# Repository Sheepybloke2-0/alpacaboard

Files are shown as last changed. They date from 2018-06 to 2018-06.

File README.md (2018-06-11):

# Alpaca-board
An Open Source keyboard designed for Kailh Low Profile Switches.

This keyboard is meant to be ultra portable, using the [Kailh Low Profile](https://novelkeys.xyz/products/kailh-low-profile-switches)
switches and a minimalist design. That being said, I wanted to add all the keys that I miss when typing on my 40% and 60% boards, such as arrow
keys, Home, End, Delete, Up and Down. I also decided to use USB C as the connector, since I perfer the form factor and flexablility for future
designs. The keyboard will be fully customizable through QMK, the software of which will be coming up soon.

# Goals
 - Be portable yet useful
 - Have RGB underglow, maybe backlighting?
 - Try out different PCB and key layouts for something new and exciting
 - Utilize current Kailh Low Profile switches and keycaps 
 - Add Bluetooth capablilities!

# Software and Tools
Schematic and PCB design was done in [KiCAD](http://kicad-pcb.org/). Because I'm lazy, the routing was done by [Freerouting](https://github.com/freerouting/freerouting).

# References
 - [ATmega32U4 Datasheet](https://cdn.sparkfun.com/datasheets/Dev/Arduino/Boards/ATMega32U4.pdf)
 - [PJRC Wiki](https://www.pjrc.com/)
 - [OLKB Basic Schematics](https://github.com/olkb/olkb_parts/blob/master/planck/schematic.pdf)
    - Used this as a basic reference on how to use the ATmega in the system. Great starting point for figuring out what to Google!
 - [Kailh Low Profile CAD](https://github.com/keyboardio/keyswitch_documentation/blob/master/datasheets/Kailh/PG135001D02.pdf)
    - I believe this is still the design of the current switches. 
 - [QMK's handwiring guide](https://docs.qmk.fm/#/hand_wire)
    - Helps you understand the basics of keyboard design and the key matrix
 - [USB C connector pinouts](https://en.wikipedia.org/wiki/USB-C#Connector_pinouts)
 - [Guide to the key matrix](http://blog.komar.be/how-to-make-a-keyboard-the-matrix/)
    - Great and informative guide to keyboard design
 - [Featherwing ATmega32u4 with BLE](https://www.adafruit.com/product/2829)
 - [MCP23008 I2C GPIO Expander](https://www.adafruit.com/product/593)
 - [Max keyboard key size chart](http://www.maxkeyboard.com/mechanical-keycap-layout-and-size-chart.html)
 - [Bunch of keyboard parts](https://github.com/keebio/Keebio-Parts.pretty)
 - [Featherwing KiCAD Model](https://forum.kicad.info/t/designing-featherwings-in-kicad/6115/2)
    - Use the bottom one
    
# Version 0.2 
After making the schematic and layout for V0.1, I decided to change the components to thru-hole and use a micro-controller for 
easier soldering and assembly. The other reason is because of the Featherwing ATMega32u4 with BLE support. This has a handle
LiPo charging circuit and BLE support for most devices, specifically mobile. For some computers a converter may be needed. 
However, in order to make this work, I had to add a GPIO expander, since most of the pins on the Featherwing are needed for
other functions, such as the Bluetooth and charging. The expander talks via I2C and is addressed at `000`. This expander also
allows for the RGB underglow I wanted to include. Now, it's on to fabrication and software!

# License
I hope that by keeping this project Open Source, other designers can use my work as a base to get up and running quickly. Feel free to use my 
notes and ideas, but please adhere to the [Open Hardware License](https://www.oshwa.org/definition/).

Enjoy!

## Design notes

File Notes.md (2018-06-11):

# Notes on Working with the ATMega32U4 for Keyboard Design

1. `PB7` is the [standard port](https://docs.qmk.fm/#/feature_backlight) in QMK for the `LED_DATA` line.
2. `PE2` is a reset with connections to the bootloader. I think it is needed for
   flashing the system. [See PE2 on pg 80](https://cdn.sparkfun.com/datasheets/Dev/Arduino/Boards/ATMega32U4.pdf)
3. Use `ATMega32U4RC-AU`. `RC` means it has an internal oscillator, and `AU` means the
   package has the leads exposed.
4. I don't think we need to have `XTAL` connected, since we are using an internal oscillator.
5. Connect all the Vccs and GNDs together, since we aren't doing anything fancy with the ADC
6. Filter the Vcc with a couple of caps. Doesn't need to be huge, but it's 5c for two 10uF caps, so worth it for the extra filtering.
7. For the shield, assume the GND is the same as referance.
8. [See this page](https://github.com/keyboardio/keyswitch_documentation/blob/master/datasheets/Kailh/PG135001D02.pdf) for the switch footprint.
9. Think foot print of PCB is 70mmx250mm
10. 330mmX98mm
11. Mount0 = 58.42mm X 168.4mm
12. Mount1 = 20.32mm X 28.7mm
13. Mount2 = 22.61mm X 39.88mm
14. Mount3 = 4.1mm X 47mm
15. Mount4 = 19.1mm X 22.35mm

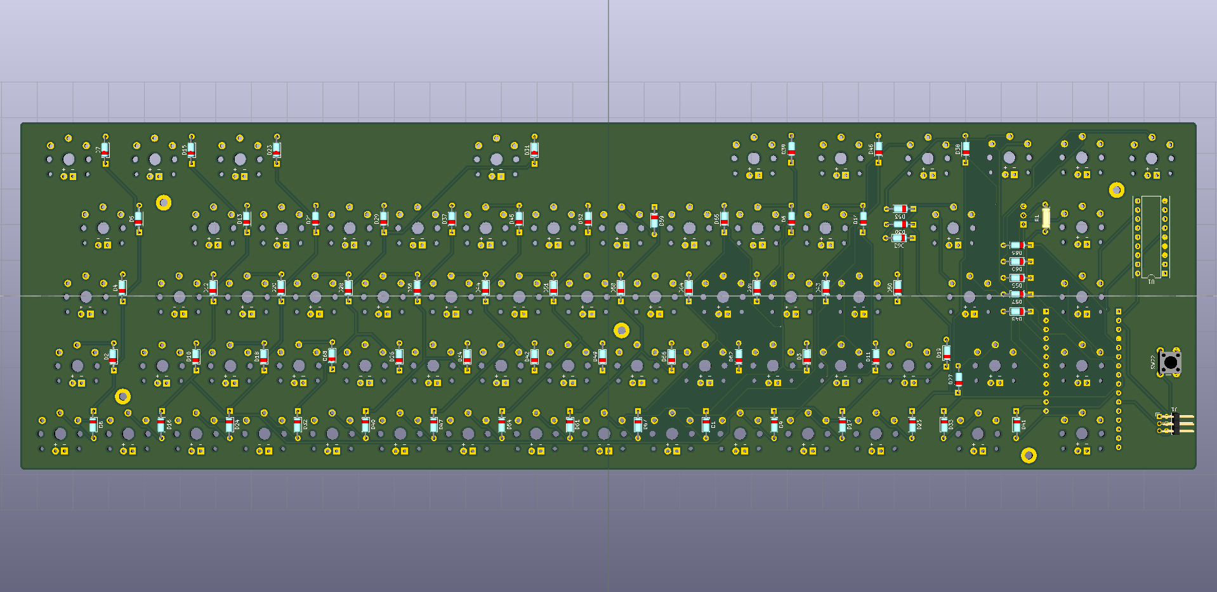
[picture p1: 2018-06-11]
alpacaboard_schem_v0.2_Back.png

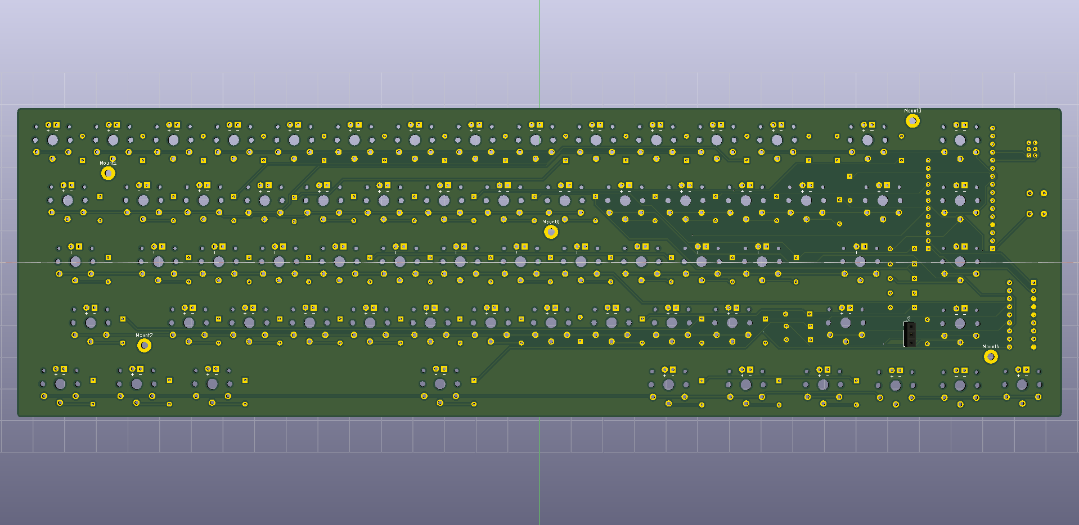
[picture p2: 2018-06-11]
alpacaboard_schem_v0.2_Front.png

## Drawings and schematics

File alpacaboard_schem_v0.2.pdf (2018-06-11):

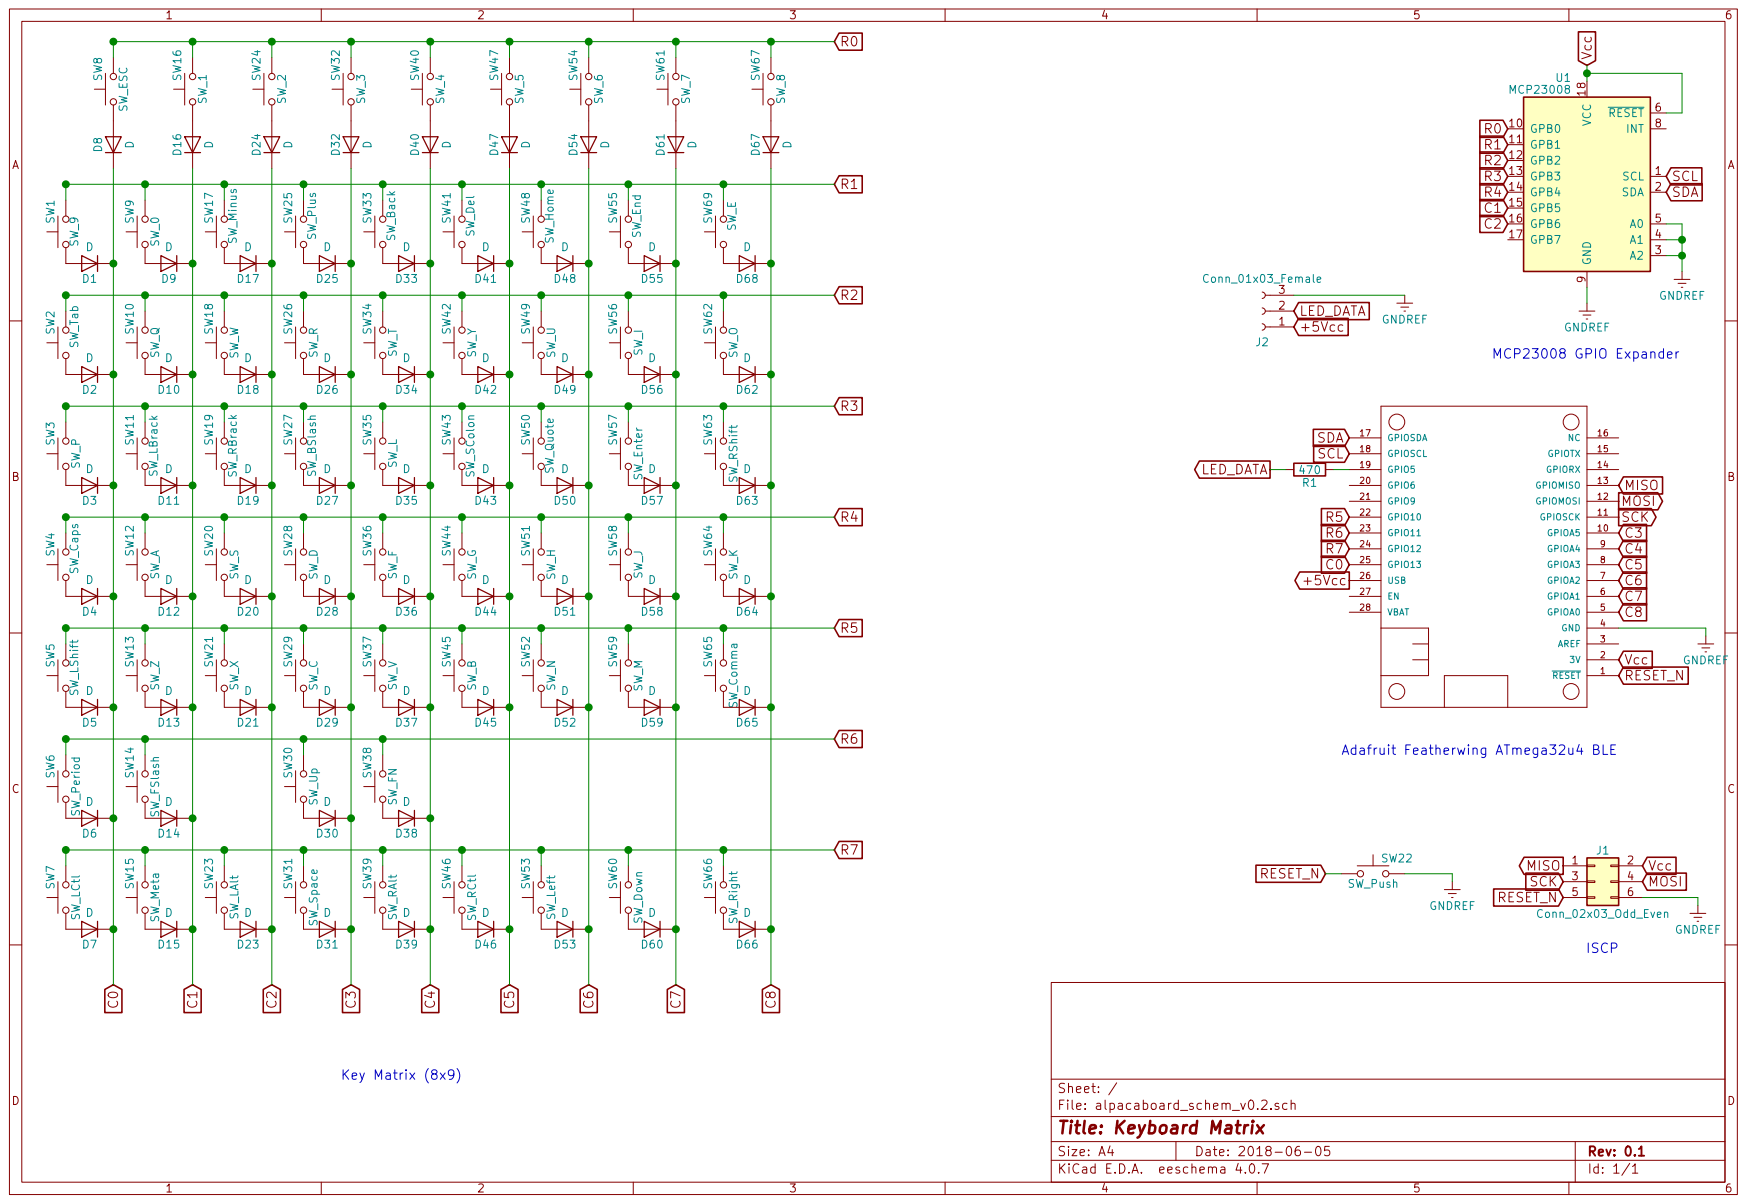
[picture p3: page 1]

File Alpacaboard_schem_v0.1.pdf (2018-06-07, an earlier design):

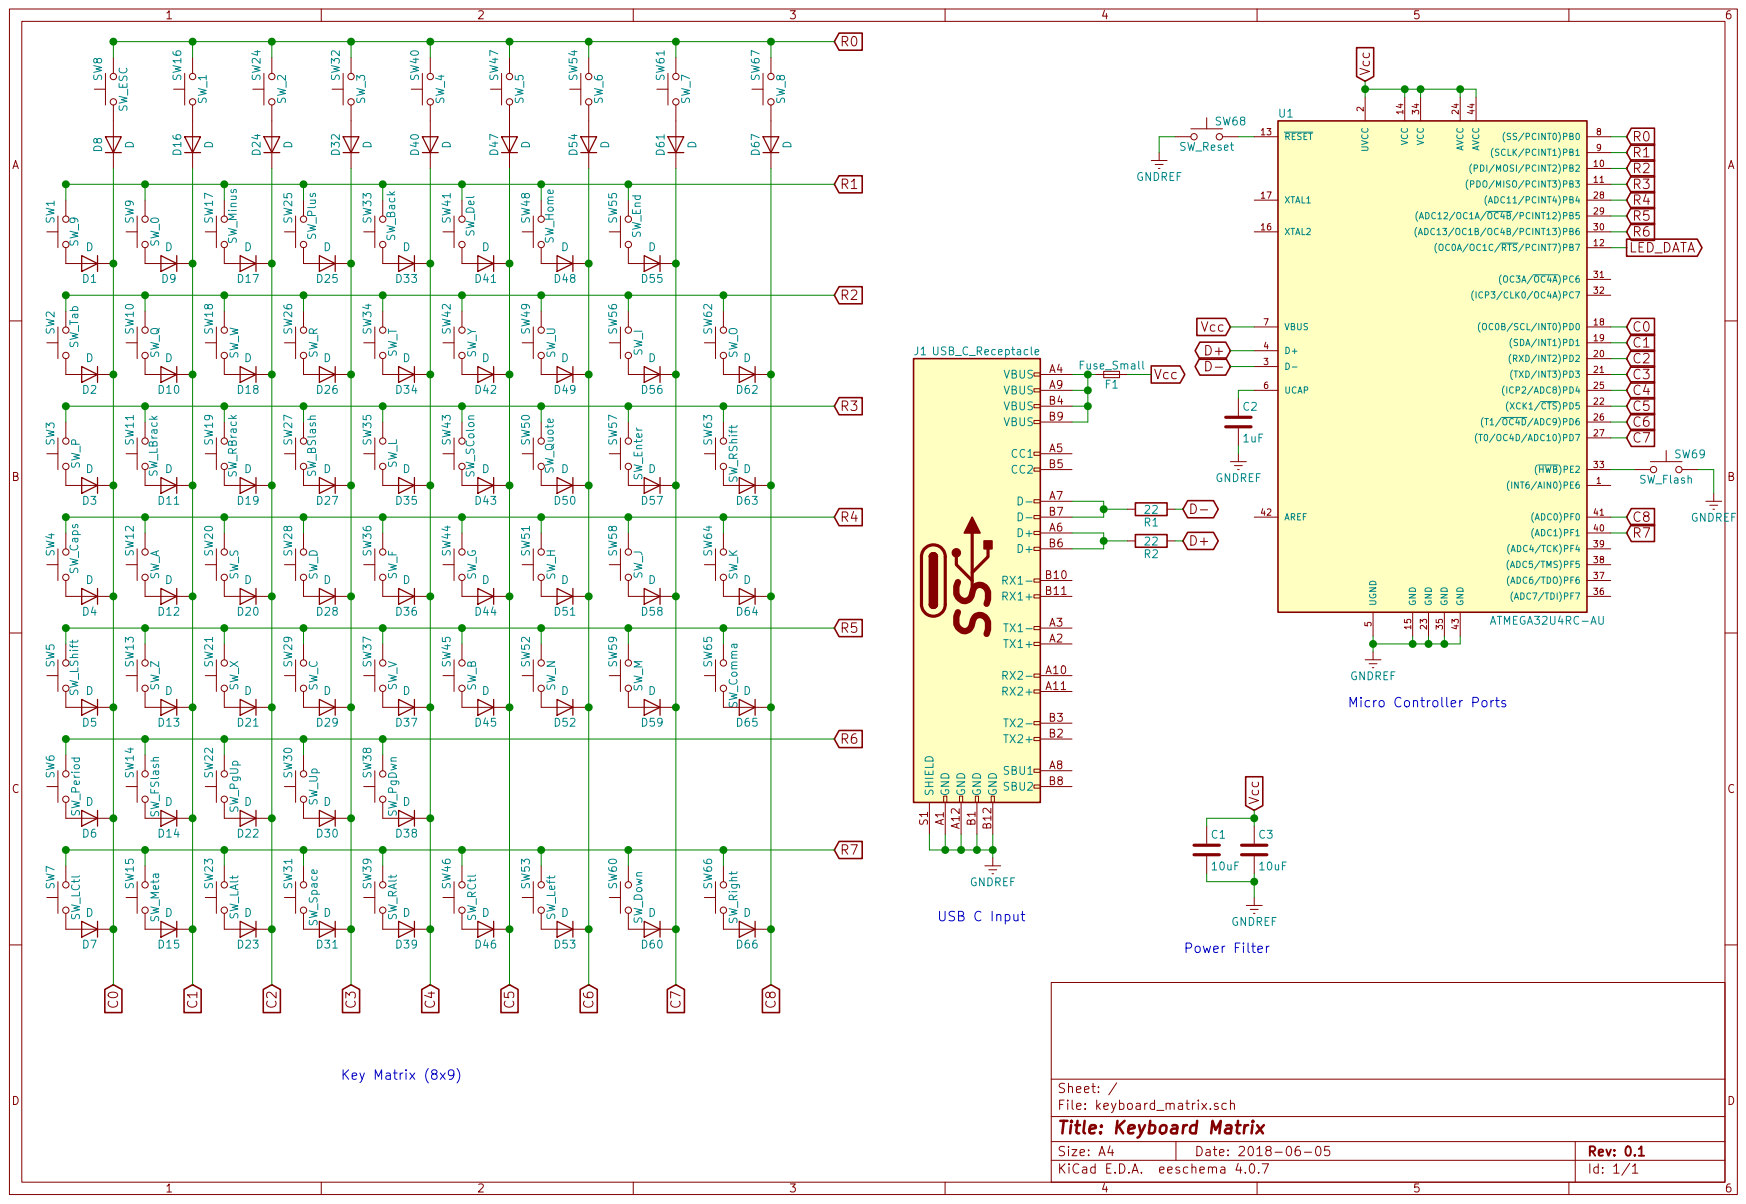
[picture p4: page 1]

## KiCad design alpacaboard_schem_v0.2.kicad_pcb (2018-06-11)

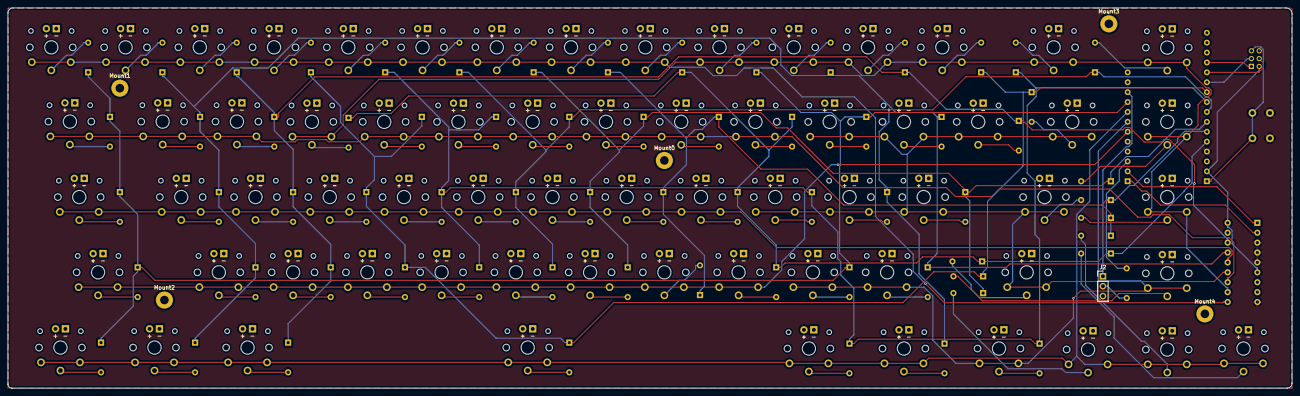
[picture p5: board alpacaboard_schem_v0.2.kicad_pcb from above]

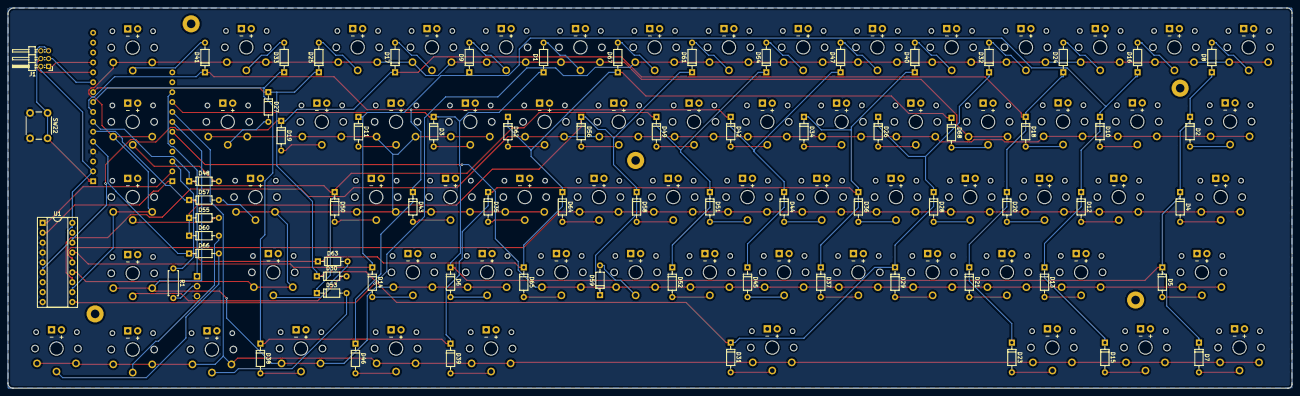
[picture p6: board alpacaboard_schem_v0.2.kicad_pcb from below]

Board: 2 copper layers, 329.4 x 97.5 mm, 145 parts (72 on the bottom side), 95 nets.

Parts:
D1, D2, D3, D4, D5, D6, D7, D8, D9, D10, D11, D12, D13, D14, D15, D16, D17, D18, D19, D20, D21, D23, D24, D25, D26, D27, D28, D29, D30, D31, D32, D33, D34, D35, D36, D37, D38, D39, D40, D41, D42, D43, D44, D45, D46, D47, D48, D49, D50, D51, D52, D53, D54, D55, D56, D57, D58, D59, D60, D61, D62, D63, D64, D65, D66, D67, D68: D; D_DO-35_SOD27_P7.62mm_Horizontal
J1: Conn_02x03_Odd_Even; Pin_Header_Angled_2x03_Pitch2.00mm
J2: Conn_01x03_Female; Socket_Strip_Straight_1x03_Pitch2.54mm
MS1: FEATHERWING; PCB_FeatherWing
Mount0, Mount1, Mount2, Mount3, Mount4: MountingHole_2.2mm_M2_Pad
R1: 470; R_Axial_DIN0207_L6.3mm_D2.5mm_P7.62mm_Horizontal
SW1: SW_9; Kailh-PG1350-1u-reversible-flip
SW2: SW_Tab; Kailh-PG1350-1u-reversible-flip
SW3: SW_P; Kailh-PG1350-1u-reversible-flip
SW4: SW_Caps; Kailh-PG1350-1u-reversible-flip
SW5: SW_LShift; Kailh-PG1350-1u-reversible-flip
SW6: SW_Period; Kailh-PG1350-1u-reversible-flip
SW7: SW_LCtl; Kailh-PG1350-1u-reversible-flip
SW8: SW_ESC; Kailh-PG1350-1u-reversible-flip
SW9: SW_0; Kailh-PG1350-1u-reversible-flip
SW10: SW_Q; Kailh-PG1350-1u-reversible-flip
SW11: SW_LBrack; Kailh-PG1350-1u-reversible-flip
SW12: SW_A; Kailh-PG1350-1u-reversible-flip
SW13: SW_Z; Kailh-PG1350-1u-reversible-flip
SW14: SW_FSlash; Kailh-PG1350-1u-reversible-flip
SW15: SW_Meta; Kailh-PG1350-1u-reversible-flip
SW16: SW_1; Kailh-PG1350-1u-reversible-flip
SW17: SW_Minus; Kailh-PG1350-1u-reversible-flip
SW18: SW_W; Kailh-PG1350-1u-reversible-flip
SW19: SW_RBrack; Kailh-PG1350-1u-reversible-flip
SW20: SW_S; Kailh-PG1350-1u-reversible-flip
SW21: SW_X; Kailh-PG1350-1u-reversible-flip
SW22: SW_Push; SW_PUSH_6mm
SW23: SW_LAlt; Kailh-PG1350-1u-reversible-flip
SW24: SW_2; Kailh-PG1350-1u-reversible-flip
SW25: SW_Plus; Kailh-PG1350-1u-reversible-flip
SW26: SW_R; Kailh-PG1350-1u-reversible-flip
SW27: SW_BSlash; Kailh-PG1350-1u-reversible-flip
SW28: SW_D; Kailh-PG1350-1u-reversible-flip
SW29: SW_C; Kailh-PG1350-1u-reversible-flip
SW30: SW_Up; Kailh-PG1350-1u-reversible-flip
SW31: SW_Space; Kailh-PG1350-1u-reversible-flip
SW32: SW_3; Kailh-PG1350-1u-reversible-flip
SW33: SW_Back; Kailh-PG1350-1u-reversible-flip
SW34: SW_T; Kailh-PG1350-1u-reversible-flip
SW35: SW_L; Kailh-PG1350-1u-reversible-flip
SW36: SW_F; Kailh-PG1350-1u-reversible-flip
SW37: SW_V; Kailh-PG1350-1u-reversible-flip
SW38: SW_FN; Kailh-PG1350-1u-reversible-flip
SW39: SW_RAlt; Kailh-PG1350-1u-reversible-flip
SW40: SW_4; Kailh-PG1350-1u-reversible-flip
SW41: SW_Del; Kailh-PG1350-1u-reversible-flip
SW42: SW_Y; Kailh-PG1350-1u-reversible-flip
SW43: SW_SColon; Kailh-PG1350-1u-reversible-flip
SW44: SW_G; Kailh-PG1350-1u-reversible-flip
SW45: SW_B; Kailh-PG1350-1u-reversible-flip
SW46: SW_RCtl; Kailh-PG1350-1u-reversible-flip
SW47: SW_5; Kailh-PG1350-1u-reversible-flip
SW48: SW_Home; Kailh-PG1350-1u-reversible-flip
SW49: SW_U; Kailh-PG1350-1u-reversible-flip
SW50: SW_Quote; Kailh-PG1350-1u-reversible-flip
SW51: SW_H; Kailh-PG1350-1u-reversible-flip
SW52: SW_N; Kailh-PG1350-1u-reversible-flip
SW53: SW_Left; Kailh-PG1350-1u-reversible-flip
SW54: SW_6; Kailh-PG1350-1u-reversible-flip
SW55: SW_End; Kailh-PG1350-1u-reversible-flip
SW56: SW_I; Kailh-PG1350-1u-reversible-flip
SW57: SW_Enter; Kailh-PG1350-1u-reversible-flip
SW58: SW_J; Kailh-PG1350-1u-reversible-flip
SW59: SW_M; Kailh-PG1350-1u-reversible-flip
SW60: SW_Down; Kailh-PG1350-1u-reversible-flip
SW61: SW_7; Kailh-PG1350-1u-reversible-flip
SW62: SW_O; Kailh-PG1350-1u-reversible-flip
SW63: SW_RShift; Kailh-PG1350-1u-reversible-flip
SW64: SW_K; Kailh-PG1350-1u-reversible-flip
SW65: SW_Comma; Kailh-PG1350-1u-reversible-flip
SW66: SW_Right; Kailh-PG1350-1u-reversible-flip
SW67: SW_8; Kailh-PG1350-1u-reversible-flip
SW69: SW_E; Kailh-PG1350-1u-reversible-flip
U1: MCP23008; DIP-18_W7.62mm_Socket

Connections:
+5Vcc: J2.1, MS1.26
C0: D1.1, D2.1, D3.1, D4.1, D5.1, D6.1, D7.1, D8.1, MS1.25
C1: D9.1, D10.1, D11.1, D12.1, D13.1, D14.1, D15.1, D16.1, U1.15
C2: D17.1, D18.1, D19.1, D20.1, D21.1, D23.1, D24.1, U1.16
C3: D25.1, D26.1, D27.1, D28.1, D29.1, D30.1, D31.1, D32.1, MS1.10
C4: D33.1, D34.1, D35.1, D36.1, D37.1, D38.1, D39.1, D40.1, MS1.9
C5: D41.1, D42.1, D43.1, D44.1, D45.1, D46.1, D47.1, MS1.8
C6: D48.1, D49.1, D50.1, D51.1, D52.1, D53.1, D54.1, MS1.7
C7: D55.1, D56.1, D57.1, D58.1, D59.1, D60.1, D61.1, MS1.6
C8: D62.1, D63.1, D64.1, D65.1, D66.1, D67.1, D68.1, MS1.5
GNDREF: J1.6, J2.3, MS1.4, SW22.2, U1.3, U1.4, U1.5, U1.9
LED_DATA: J2.2, R1.2
MISO: J1.1, MS1.13
MOSI: J1.4, MS1.12
unnamed: D1.2, SW1.1
unnamed: D2.2, SW2.1
unnamed: D3.2, SW3.1
unnamed: D4.2, SW4.1
unnamed: D5.2, SW5.1
unnamed: D6.2, SW6.1
unnamed: D7.2, SW7.1
unnamed: D8.2, SW8.1
unnamed: D9.2, SW9.1
unnamed: D10.2, SW10.1
unnamed: D11.2, SW11.1
unnamed: D12.2, SW12.1
unnamed: D13.2, SW13.1
unnamed: D14.2, SW14.1
unnamed: D15.2, SW15.1
unnamed: D16.2, SW16.1
unnamed: D17.2, SW17.1
unnamed: D18.2, SW18.1
unnamed: D19.2, SW19.1
unnamed: D20.2, SW20.1
unnamed: D21.2, SW21.1
unnamed: D23.2, SW23.1
unnamed: D24.2, SW24.1
unnamed: D25.2, SW25.1
unnamed: D26.2, SW26.1
unnamed: D27.2, SW27.1
unnamed: D28.2, SW28.1
unnamed: D29.2, SW29.1
unnamed: D30.2, SW30.1
unnamed: D31.2, SW31.1
unnamed: D32.2, SW32.1
unnamed: D33.2, SW33.1
unnamed: D34.2, SW34.1
unnamed: D35.2, SW35.1
unnamed: D36.2, SW36.1
unnamed: D37.2, SW37.1
unnamed: D38.2, SW38.1
unnamed: D39.2, SW39.1
unnamed: D40.2, SW40.1
unnamed: D41.2, SW41.1
unnamed: D42.2, SW42.1
unnamed: D43.2, SW43.1
unnamed: D44.2, SW44.1
unnamed: D45.2, SW45.1
unnamed: D46.2, SW46.1
unnamed: D47.2, SW47.1
unnamed: D48.2, SW48.1
unnamed: D49.2, SW49.1
unnamed: D50.2, SW50.1
unnamed: D51.2, SW51.1
unnamed: D52.2, SW52.1
unnamed: D53.2, SW53.1
unnamed: D54.2, SW54.1
unnamed: D55.2, SW55.1
unnamed: D56.2, SW56.1
unnamed: D57.2, SW57.1
unnamed: D58.2, SW58.1
unnamed: D59.2, SW59.1
unnamed: D60.2, SW60.1
unnamed: D61.2, SW61.1
unnamed: D62.2, SW62.1
unnamed: D63.2, SW63.1
unnamed: D64.2, SW64.1
unnamed: D65.2, SW65.1
unnamed: D66.2, SW66.1
unnamed: D67.2, SW67.1
unnamed: D68.2, SW69.1
unnamed: MS1.19, R1.1
R0: SW8.2, SW16.2, SW24.2, SW32.2, SW40.2, SW47.2, SW54.2, SW61.2, SW67.2, U1.10
R1: SW1.2, SW9.2, SW17.2, SW25.2, SW33.2, SW41.2, SW48.2, SW55.2, SW69.2, U1.11
R2: SW2.2, SW10.2, SW18.2, SW26.2, SW34.2, SW42.2, SW49.2, SW56.2, SW62.2, U1.12
R3: SW3.2, SW11.2, SW19.2, SW27.2, SW35.2, SW43.2, SW50.2, SW57.2, SW63.2, U1.13
R4: SW4.2, SW12.2, SW20.2, SW28.2, SW36.2, SW44.2, SW51.2, SW58.2, SW64.2, U1.14
R5: MS1.22, SW5.2, SW13.2, SW21.2, SW29.2, SW37.2, SW45.2, SW52.2, SW59.2, SW65.2
R6: MS1.23, SW6.2, SW14.2, SW30.2, SW38.2
R7: MS1.24, SW7.2, SW15.2, SW23.2, SW31.2, SW39.2, SW46.2, SW53.2, SW60.2, SW66.2
RESET_N: J1.5, MS1.1, SW22.1
SCK: J1.3, MS1.11
SCL: MS1.18, U1.1
SDA: MS1.17, U1.2
Vcc: J1.2, MS1.2, U1.6, U1.18

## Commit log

2018-06-07 Added Rev 0.1
    [alpacaboard_schem_v0.1.sch]
2018-06-11 Added Version 0.2
    [alpacaboard_schem_v0.2.dsn, alpacaboard_schem_v0.2.kicad_pcb, alpacaboard_schem_v0.2.sch]
